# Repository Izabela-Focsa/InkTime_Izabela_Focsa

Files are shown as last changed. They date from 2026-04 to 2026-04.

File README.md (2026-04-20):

# InkTime Smartwatch - Dispozitiv Wearable Open Source (Stadiu EVT)

## 📌 Prezentare Generală

**InkTime** este un smartwatch open-source, proiectat în jurul microcontrolerului **Nordic nRF52840**, cu accent pe consum redus de energie, conectivitate Bluetooth Low Energy și modularitate hardware.

Acest repository conține:

* designul PCB (Fusion Electronics)
* fișierele pentru fabricație (Gerber, BOM, Pick & Place)
* designul mecanic (Fusion 360)
* integrarea sistemului pentru etapa EVT (Engineering Validation Test)

---

## 🧩 Diagrama Bloc a Sistemului

Arhitectura sistemului este centrată în jurul microcontrolerului nRF52840, care gestionează comunicația, afișajul și senzorii.

```
        +----------------------+
        |     Baterie LiPo     |
        +----------+-----------+
                   |
            +------v------+
            |  BQ25180    |  (Încărcare)
            +------+------+
                   |
            +------v------+
            |  RT6160A    |  (Regulator 3.3V)
            +------+------+
                   |
         +---------v---------+
         |    nRF52840 MCU   |
         | (BLE + Procesare) |
         +---+----+----+-----+
             |    |    |
        SPI  |    |    | I2C
             |    |    |
   +---------v+  |   +v-----------+
   | Display   |  |   | BMA423 IMU|
   | E-Paper   |  |   +------------+
   +----------+  |
                 |
             +---v---------+
             | MAX17048    |
             | Fuel Gauge  |
             +-------------+

             +-------------+
             | DRV2605L    |
             | Vibrații    |
             +-------------+

             +-------------+
             | Butoane     |
             +-------------+
```

---

## 🔌 Funcționalitatea Hardware (Detaliat)

### 🧠 Microcontroler – nRF52840

* ARM Cortex-M4F @ 64 MHz
* Bluetooth Low Energy 5.0 integrat
* Consum foarte redus în mod sleep

Roluri principale:

* procesare date senzori
* control display
* comunicare BLE

---

### 📺 Display – E-Paper

* Interfață: **SPI**
* Consum foarte mic
* Ideal pentru afișare permanentă

---

### ⚡ Managementul Energiei

#### 🔋 BQ25180

* gestionează încărcarea bateriei LiPo
* alimentare prin USB (VBUS)

#### 🔌 RT6160A

* convertor Buck-Boost
* furnizează **3.3V stabil**
* permite funcționarea chiar și la tensiuni scăzute ale bateriei

---

### 📊 Senzori și Actuatori

#### BMA423 (Accelerometru)

* interfață I2C
* detectare mișcare / pași

#### MAX17048 (Fuel Gauge)

* monitorizare nivel baterie
* consum foarte redus

#### DRV2605L (Driver Haptic)

* controlează motorul de vibrații
* suportă feedback haptic avansat

---

### 🎮 Input Utilizator

* 3 butoane: UP / ENTER / DOWN
* conectate ca GPIO cu rezistențe pull-up interne

---

## 🔗 Mapare Pini nRF52840

| Componentă | Pini | Interfață | Motiv |
| --- | --- | --- | --- |
| **Display E-Paper** | P0.28 (SCK), P0.29 (MOSI), P0.30 (CS), P0.31 (D/C), P0.02 (RST), P0.03 (BUSY) | SPI | Transfer rapid de date |
| **Butoane** | P0.08, P0.11, P0.12 | GPIO | Input simplu |
| **Haptic Driver** | P0.16 | GPIO/PWM  | Control vibrații |
| **Senzori I2C** | P0.14 (SDA), P0.15 (SCL) | I2C | Magistrală comună |
| **Fuel Gauge** | I2C | I2C | Monitorizare baterie |

---

## 📦 Bill of Materials (BOM)

| Ref  | Componentă | Link JLCPCB | Datasheet |
| ---- | --- | --- | --- |
| U1 | nRF52840 | https://jlcpcb.com/partdetail/Nordic-nRF52840 | https://infocenter.nordicsemi.com/pdf/nRF52840_PS_v1.1.pdf |
| U2 | DRV2605L | https://jlcpcb.com/partdetail/TexasInstruments-DRV2605L | https://www.ti.com/lit/ds/symlink/drv2605l.pdf |
| U3 | MAX17048 | https://jlcpcb.com/partdetail/MaximIntegrated-MAX17048  | https://datasheets.maximintegrated.com/en/ds/MAX17048-MAX17049.pdf |
| IC1  | BQ25180 | https://jlcpcb.com/partdetail/TexasInstruments-BQ25180  | https://www.ti.com/lit/ds/symlink/bq25180.pdf |
| IC2  | BMA423 | https://jlcpcb.com/partdetail/Bosch-BMA423 | https://www.bosch-sensortec.com/media/boschsensortec/downloads/datasheets/bst-bma423-ds000.pdf |
| IC3  | RT6160A | https://jlcpcb.com/partdetail/Richtek-RT6160A | https://www.richtek.com/assets/product_file/RT6160A/DS6160A-00.pdf |
| ANT1 | Antenă BLE | https://jlcpcb.com | |

---

## ⚙️ Constrângeri și Decizii de Design

### PCB

* trasee alimentare: **0.3 mm**
* trasee semnal: **0.15 mm**
* PCB pe 2 straturi

### RF

* plan de masă continuu
* zonă fără cupru sub antenă

### Decuplare

* condensatori 100nF la <1mm de fiecare IC

### Mecanic

* toate componentele pe **TOP layer**
* design compact pentru carcasă

---

## 🔋 Estimare Consum Energetic

| Mod | Consum |
| --- | --- |
| Activ (BLE + display) | ~15–20 mA |
| Idle | ~2–5 mA |
| Sleep | <10 µA |

Baterie: ~200–300 mAh
Autonomie estimată: **2–5 zile**

---

## 🖼️ Randări și Design

Randările dispozitivului, ale PCB-ului și integrarea în carcasă pot fi găsite în folderul dedicat din repository:

👉 [Images Folder](./Images)

---

## 🛠️ Fișiere pentru Fabricație

* Gerber
* Drill files
* Pick & Place (.csv)
* BOM (.csv)

---

## 📘 Design Log

* realizare schemă electronică
* rutare PCB completă
* verificare DRC
* integrare mecanică finală

---

## 📄 Licență

Proiectul este licențiat sub **GNU General Public License v3.0**.

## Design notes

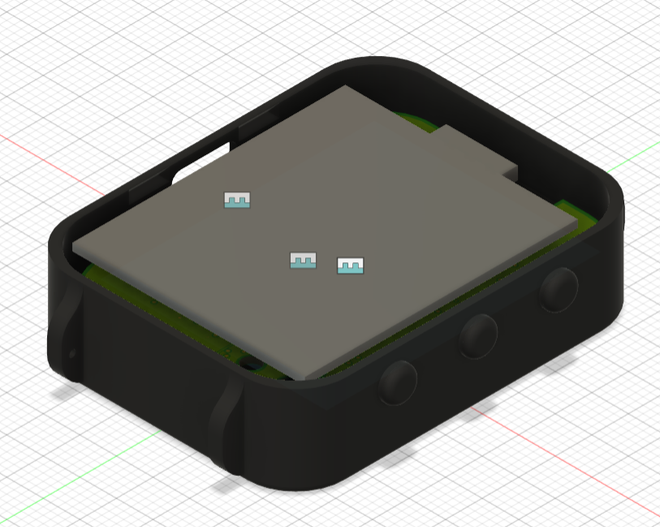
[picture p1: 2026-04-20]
Images/Cu display.png

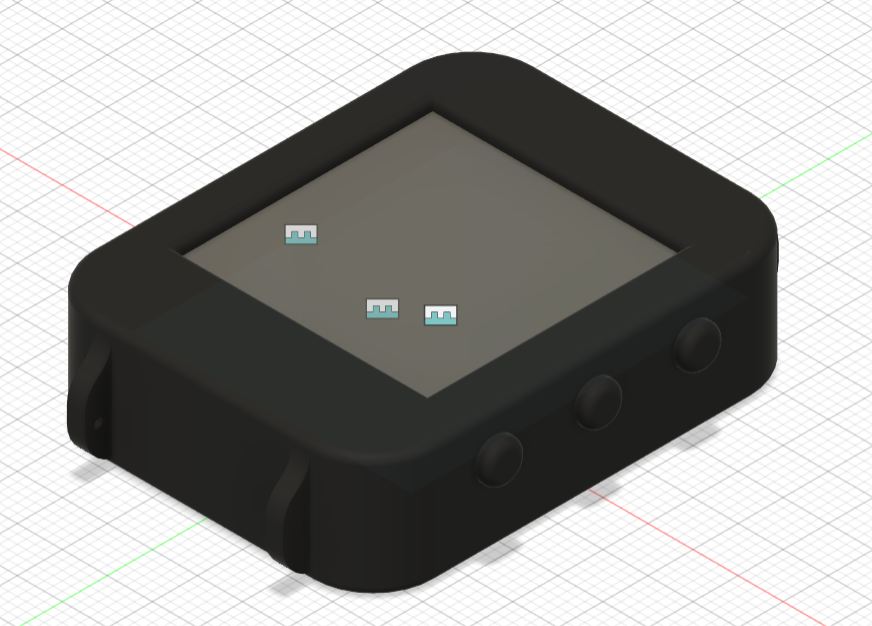
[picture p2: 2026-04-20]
Images/Cu carcasa.png

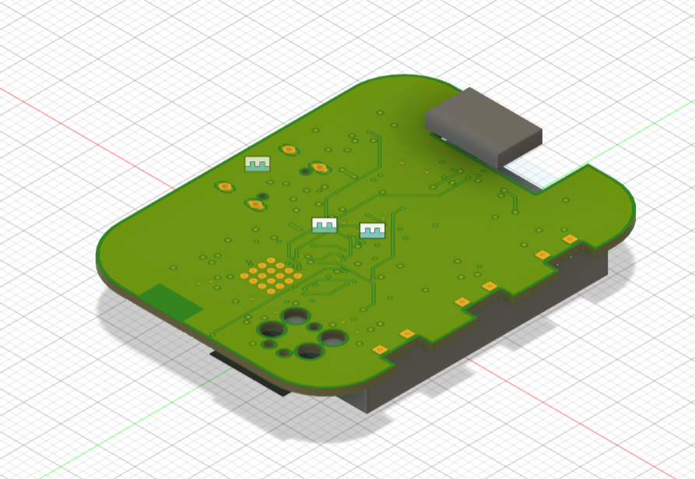
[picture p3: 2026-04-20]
Images/Placa.png

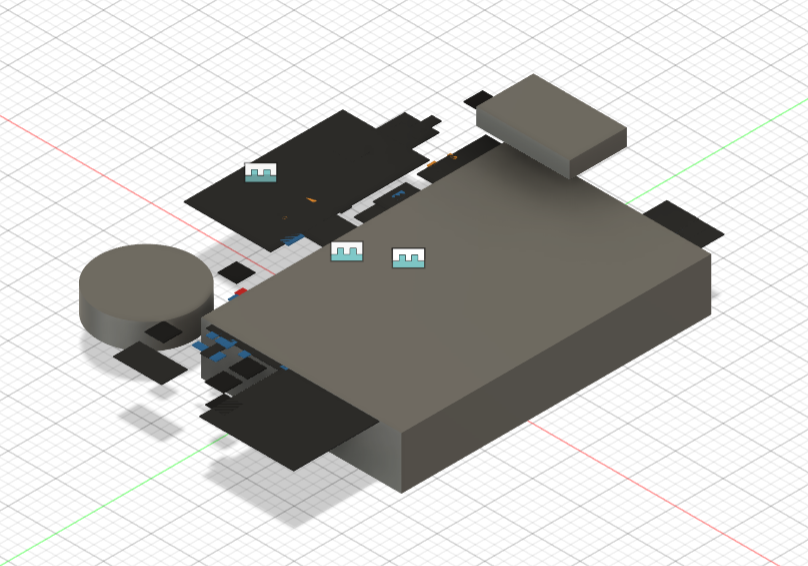
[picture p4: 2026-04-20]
Images/Packages.png

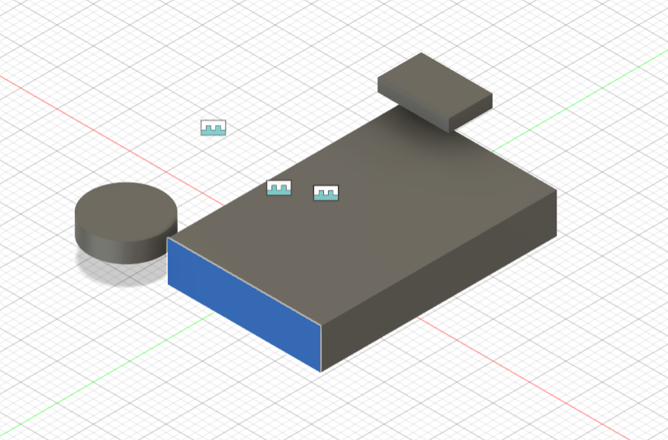
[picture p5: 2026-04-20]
Images/Baterie.png

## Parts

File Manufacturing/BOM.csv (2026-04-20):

Reference Designators | Quantity | Description | Package | Value | Manufacturer | Manufacturer Part Number | Vendor | Vendor Part Number | Top/Bottom
 | 1 | Board | Board
ANT1 | 1 | Antennas 2.45GHz ANTENNA | 2450AT18B100E_ANTC3216X140N | 2450AT18B100E |  |  |  |  | Top
C1, C2, C17, C18 | 4 | Generic chip capacitor | NORDIC_NRF_3_RESC0201_L | 12pF |  |  |  |  | Top
C1-EP-DR | 1 | Generic chip capacitor | NORDIC_NRF_3_RESC0402_L | 10uF |  |  |  |  | Top
C2-EP-DR | 1 | Generic chip capacitor | NORDIC_NRF_3_RESC0402_L | 4.7uF/25V |  |  |  |  | Top
C3, C4 | 2 | Generic chip capacitor | NORDIC_NRF_3_RESC0201_L | 1pF |  |  |  |  | Top
C5, C7, C8, C12, C19 | 5 | Generic chip capacitor | NORDIC_NRF_3_RESC0201_L | 100nF |  |  |  |  | Top
C6, C14, C20, C21 | 4 | Generic chip capacitor | NORDIC_NRF_3_RESC0402_L | 4.7µF |  |  |  |  | Top
C9 | 1 | Generic chip capacitor | NORDIC_NRF_3_RESC0201_L | 820pF |  |  |  |  | Top
C10, C13, C22 | 3 | Generic chip capacitor | NORDIC_NRF_3_RESC0201_L | N.C. |  |  |  |  | Top
C11 | 1 | Generic chip capacitor | NORDIC_NRF_3_RESC0201_L | 100pF |  |  |  |  | Top
C15 | 1 | Generic chip capacitor | NORDIC_NRF_3_RESC0402_L | 1.0µF |  |  |  |  | Top
C16 | 1 | Generic chip capacitor | NORDIC_NRF_3_RESC0201_L | 47nF |  |  |  |  | Top
C23, C27, C34, C42 | 4 | Check availability | CAPC0201X13N | 0.1uF |  |  |  |  | Top
C24 | 1 | Generic chip capacitor | NORDIC_NRF_3_RESC0201_L | 10uF |  |  |  |  | Top
C25, C33 | 2 | Generic chip capacitor | NORDIC_NRF_3_RESC0201_L | 22uF |  |  |  |  | Top
C29, C30, C31, C32, C37, C38 | 6 | Check availability | CAPC0201X13N | 1uF |  |  |  |  | Top
C39 | 1 | 0402 (1005 Metric) | PERFECT_0402_0402 | 10uF |  |  |  |  | Top
C43 | 1 | Generic chip capacitor | NORDIC_NRF_3_RESC0402_L | 4.7uF |  |  |  |  | Top
D2, D4, D5 | 3 | ON SEMICONDUCTOR - MBR0530 - DIODE, SCHOTTKY, 0.5A, 30V, SOD-123 | SOD3716X135N | MBR0530 |  |  |  |  | Top
D3 | 1 | Low Cap. ESD Protection Auto SOT-23-6 STMicroelectronics USBLC6-2SC6Y, Dual Uni-Directional TVS Diode Array, 6-Pin SOT-23 | SOT95P280X145-6N | USBLC6-2SC6Y |  |  |  |  | Top
EPD_C1, EPD_C2 | 2 | Generic chip capacitor | NORDIC_NRF_3_RESC0201_L | 1uF/50V |  |  |  |  | Top
EPD_C5 | 1 | Generic chip capacitor | NORDIC_NRF_3_RESC0201_L | 0.1uF/50V |  |  |  |  | Top
EPD_C6, EPD_C7, EPD_C8, EPD_C9, EPD_C10, EPD_C11, EPD_C12 | 7 | Generic chip capacitor | NORDIC_NRF_3_RESC0402_L | 1uF/50V |  |  |  |  | Top
IC1 | 1 | Charger IC Lithium Ion/Polymer, Lithium Iron Phosphate 8-DSBGA (1.6x1.1) | BQ25180YBGR_BGA8C40P2X4_100X155X50 | BQ25180YBGR_BQ25180YBGR |  |  |  |  | Top
IC2 | 1 | Haptic Driver for ERM/LRA with Built-In Library and Smart Loop Architecture | DRV2605YZFR_BGA9C50P3X3_144X144X62 | DRV2605YZFR |  |  |  |  | Top
IC3 | 1 | Accelerometers Triaxial low-g 12bit Acceleration Sensor | BMA423_BMA423 | BMA421 |  |  |  |  | Top
IC9 | 1 | Buck-Boost Regulator Positive Output Step-Up/Step-Down I2C DC-DC Controller IC 15-WL-CSP (BSC) (1.4x2.3) | RT6160AWSC_BGA15C40P3X5_140X230X60 | RT6160AWSC |  |  |  |  | Top
J1 | 1 | FFC & FPC Connectors 0.5mm FPC RA SMT Dual Contact 24Ckt | 503480-2400_5034802400 | 503480-2400 |  |  |  |  | Top
J2 | 1 | CABLE ADAPTER 6 POS | TC2030-IDC_TC2030IDC | TC2030-IDC |  |  |  |  | Top
J4 | 1 | Check availability | KINGHELM_KH-TYPE-C-16P | KH-TYPE-C-16P |  |  |  |  | Top
L1 | 1 | Generic chip inductor | NORDIC_NRF_2_RESC0402_L | 3.9nH |  |  |  |  | Top
L2 | 1 | Generic chip inductor | NORDIC_NRF_2_RESC0402_L | 10µH |  |  |  |  | Top
L3 | 1 | Generic chip inductor | NORDIC_NRF_2_RESC0402_L | 15nH |  |  |  |  | Top
L5 | 1 |  | ESP32_C6_LIBRARY_2_IND_4828-WE-TPC_WRE | 68uH |  |  |  |  | Top
L7 | 1 | SMD / SMT Inductors (Coils), L=0.47?H, L x W x T : | MLP2016SR47MT0S1_INDC2016X100N | FTC252012SR47MBCA |  |  |  |  | Top
Q1 | 1 | P-channel MOSFETs | ESP32_WROVER_SPARKFUN-DISCRETESEMI_SOT23-3 | 20V/4.2A/52mΩ/1.4W |  |  |  |  | Top
Q3 | 1 | MOSFET N-Ch 30V 1.5A TrenchFET SC70 Vishay Si1308EDL-T1-GE3 N-channel MOSFET Transistor, 1.5 A, 30 V, 3-Pin SC-70 | SOT65P210X110-3N | SI1308EDL-T1-GE3 |  |  |  |  | Top
R_PWR_EPD, R2_EP_DR | 2 | 7.68k 0201 Thin Film Surface Mount Fixed Resistor +/-0.5% 0.031W CPF0201D7K68C1 | CPF0201D7K68C1_0201 | 10K |  |  |  |  | Top
R_TYPE_SEL | 1 | 7.68k 0201 Thin Film Surface Mount Fixed Resistor +/-0.5% 0.031W CPF0201D7K68C1 | CPF0201D7K68C1_0201 | 2.2 |  |  |  |  | Top
R1_EP_ED | 1 | 7.68k 0201 Thin Film Surface Mount Fixed Resistor +/-0.5% 0.031W CPF0201D7K68C1 | CPF0201D7K68C1_0201 | 0.47 |  |  |  |  | Top
R1_USB, R2_USB | 2 | 7.68k 0201 Thin Film Surface Mount Fixed Resistor +/-0.5% 0.031W CPF0201D7K68C1 | CPF0201D7K68C1_0201 | 5K1 |  |  |  |  | Top
R2, R4 | 2 | 7.68k 0201 Thin Film Surface Mount Fixed Resistor +/-0.5% 0.031W CPF0201D7K68C1 | CPF0201D7K68C1_0201 | 0 |  |  |  |  | Top
R3 | 1 | 7.68k 0201 Thin Film Surface Mount Fixed Resistor +/-0.5% 0.031W CPF0201D7K68C1 | R0201 | 0 |  |  |  |  | Top
R5, R7, R8 | 3 | 7.68k 0201 Thin Film Surface Mount Fixed Resistor +/-0.5% 0.031W CPF0201D7K68C1 | R0201 | 10k |  |  |  |  | Top
R9 | 1 | 7.68k 0201 Thin Film Surface Mount Fixed Resistor +/-0.5% 0.031W CPF0201D7K68C1 | R0201 | 10K |  |  |  |  | Top
R17, R18 | 2 | 7.68k 0201 Thin Film Surface Mount Fixed Resistor +/-0.5% 0.031W CPF0201D7K68C1 | CPF0201D7K68C1_0201 | 3K3 |  |  |  |  | Top
SJ1 | 1 | SMD solder JUMPER | JUMPER_SJ | N.C |  |  |  |  | Top
SW_DN, SW_ENT, SW_UP | 3 |  | SW_EVP-AKE31A_PAN | 2025-10-22_07-23-44_LIBRARY_EVP-AKE31ASW_EVP-AKE31A_PAN |  |  |  |  | Top
TP_3.3V, TP_3V3, TP_BAT_GND, TP_GND, TP_ON, TP_OP, TP_RESET, TP_SCL, TP_SDA, TP_SWDCLK, TP_SWDIO, TP_SWO, TP_VBAT, TP_VREG | 14 | Test pad | HECTOR_WATCH_1_TP20R | HECTOR_WATCH_1_TPTP20R |  |  |  |  | Top
U1 | 1 | nRF52840 | NORDIC_NRF_4_AQFN50P700X700X85_HS-74N | NRF52840_QF |  |  |  |  | Top
U3 | 1 | Check availability | SON50P200X200X80-9N | MAX17048G+T10 |  |  |  |  | Top
X1 | 1 |  | NORDIC_NRF_BT-XTAL_2016_N | 32MHz |  |  |  |  | Top
X2 | 1 |  | NORDIC_NRF_1_XTAL_3215_N | 32.768kHz |  |  |  |  | Top

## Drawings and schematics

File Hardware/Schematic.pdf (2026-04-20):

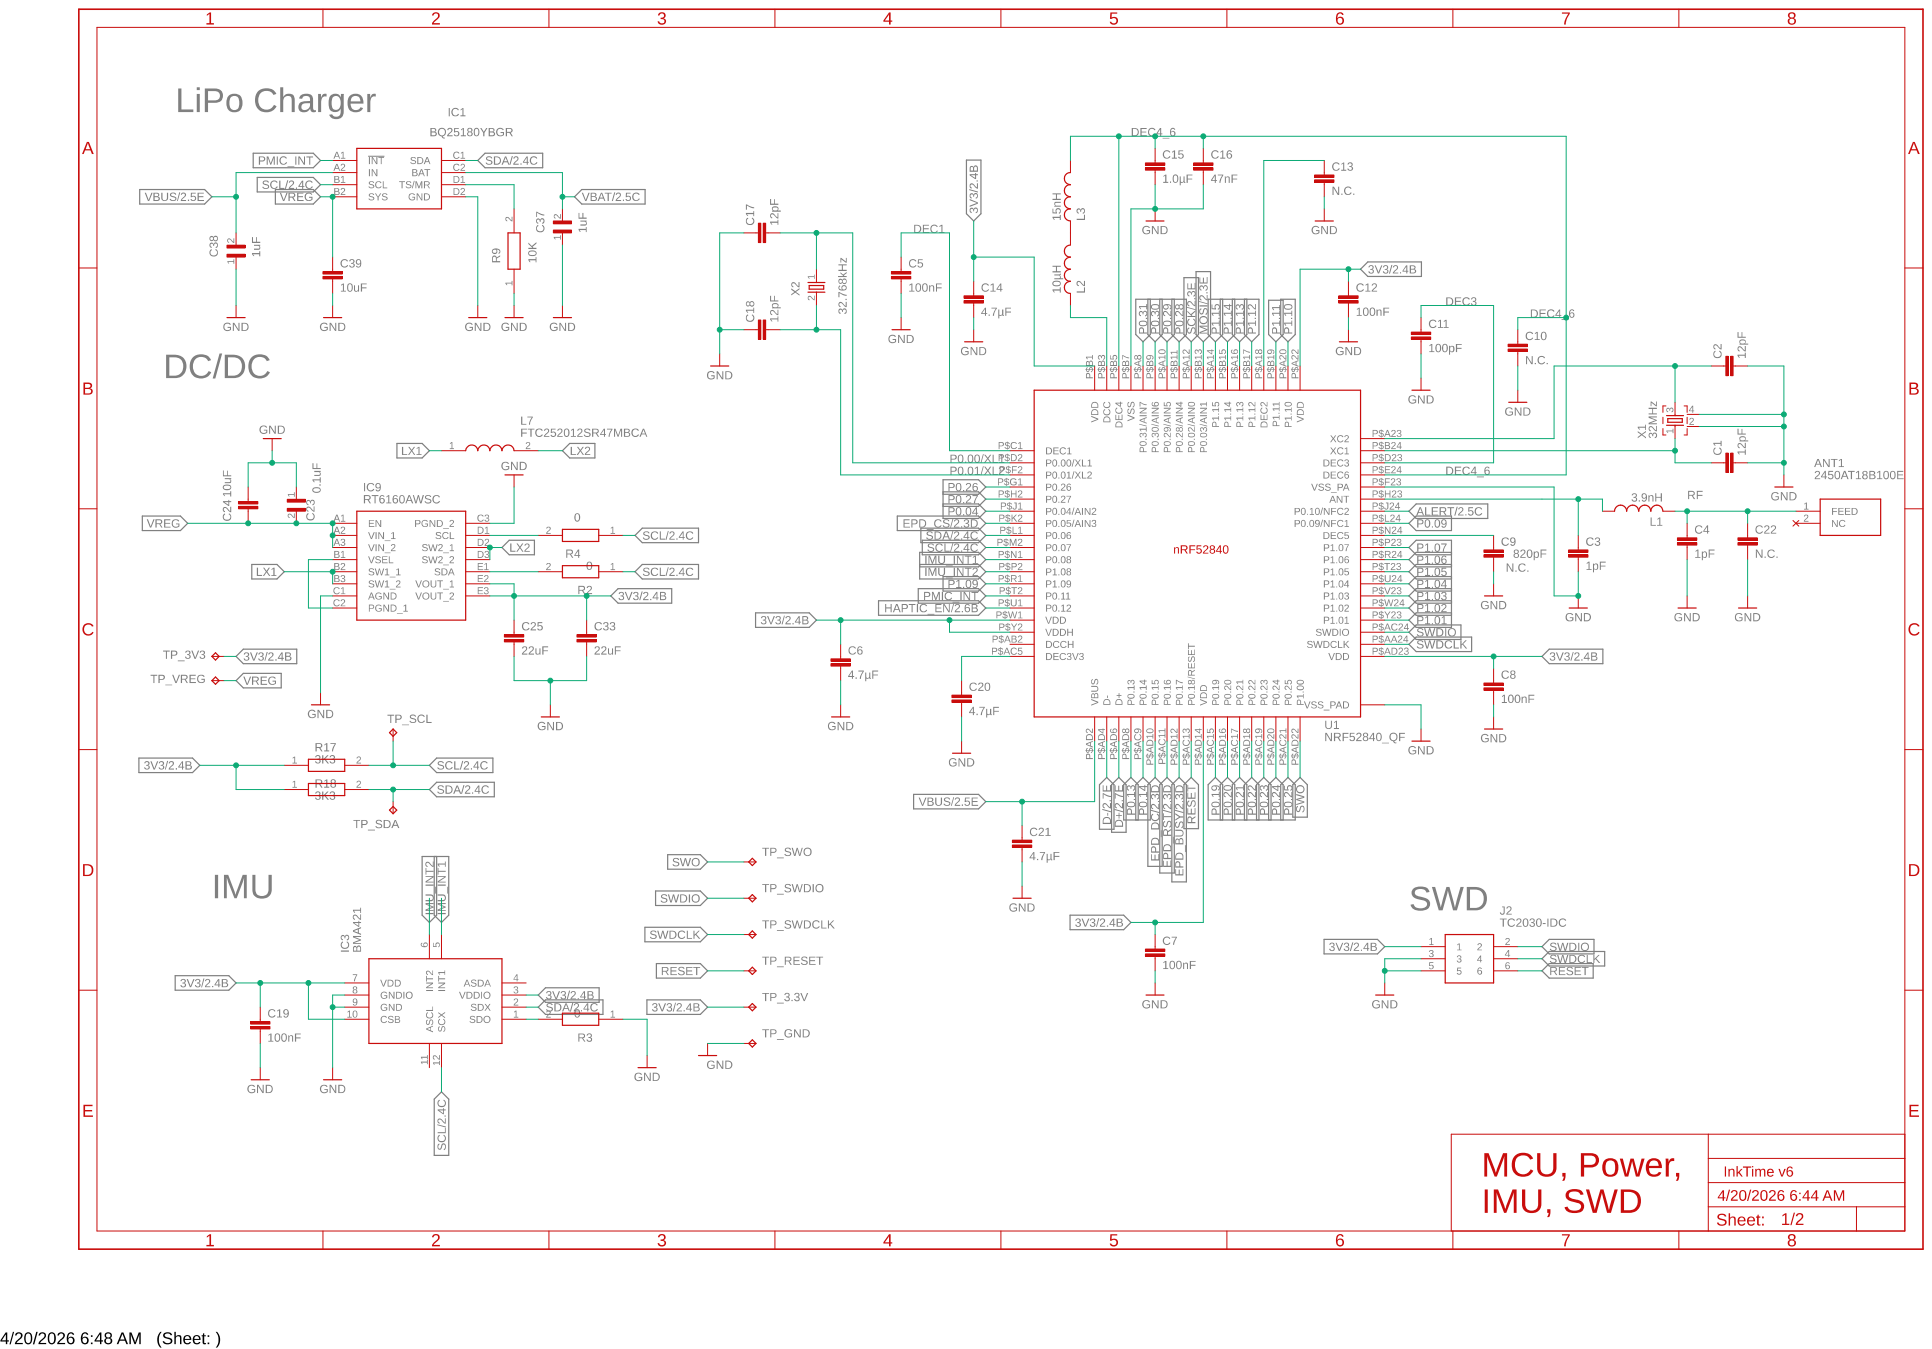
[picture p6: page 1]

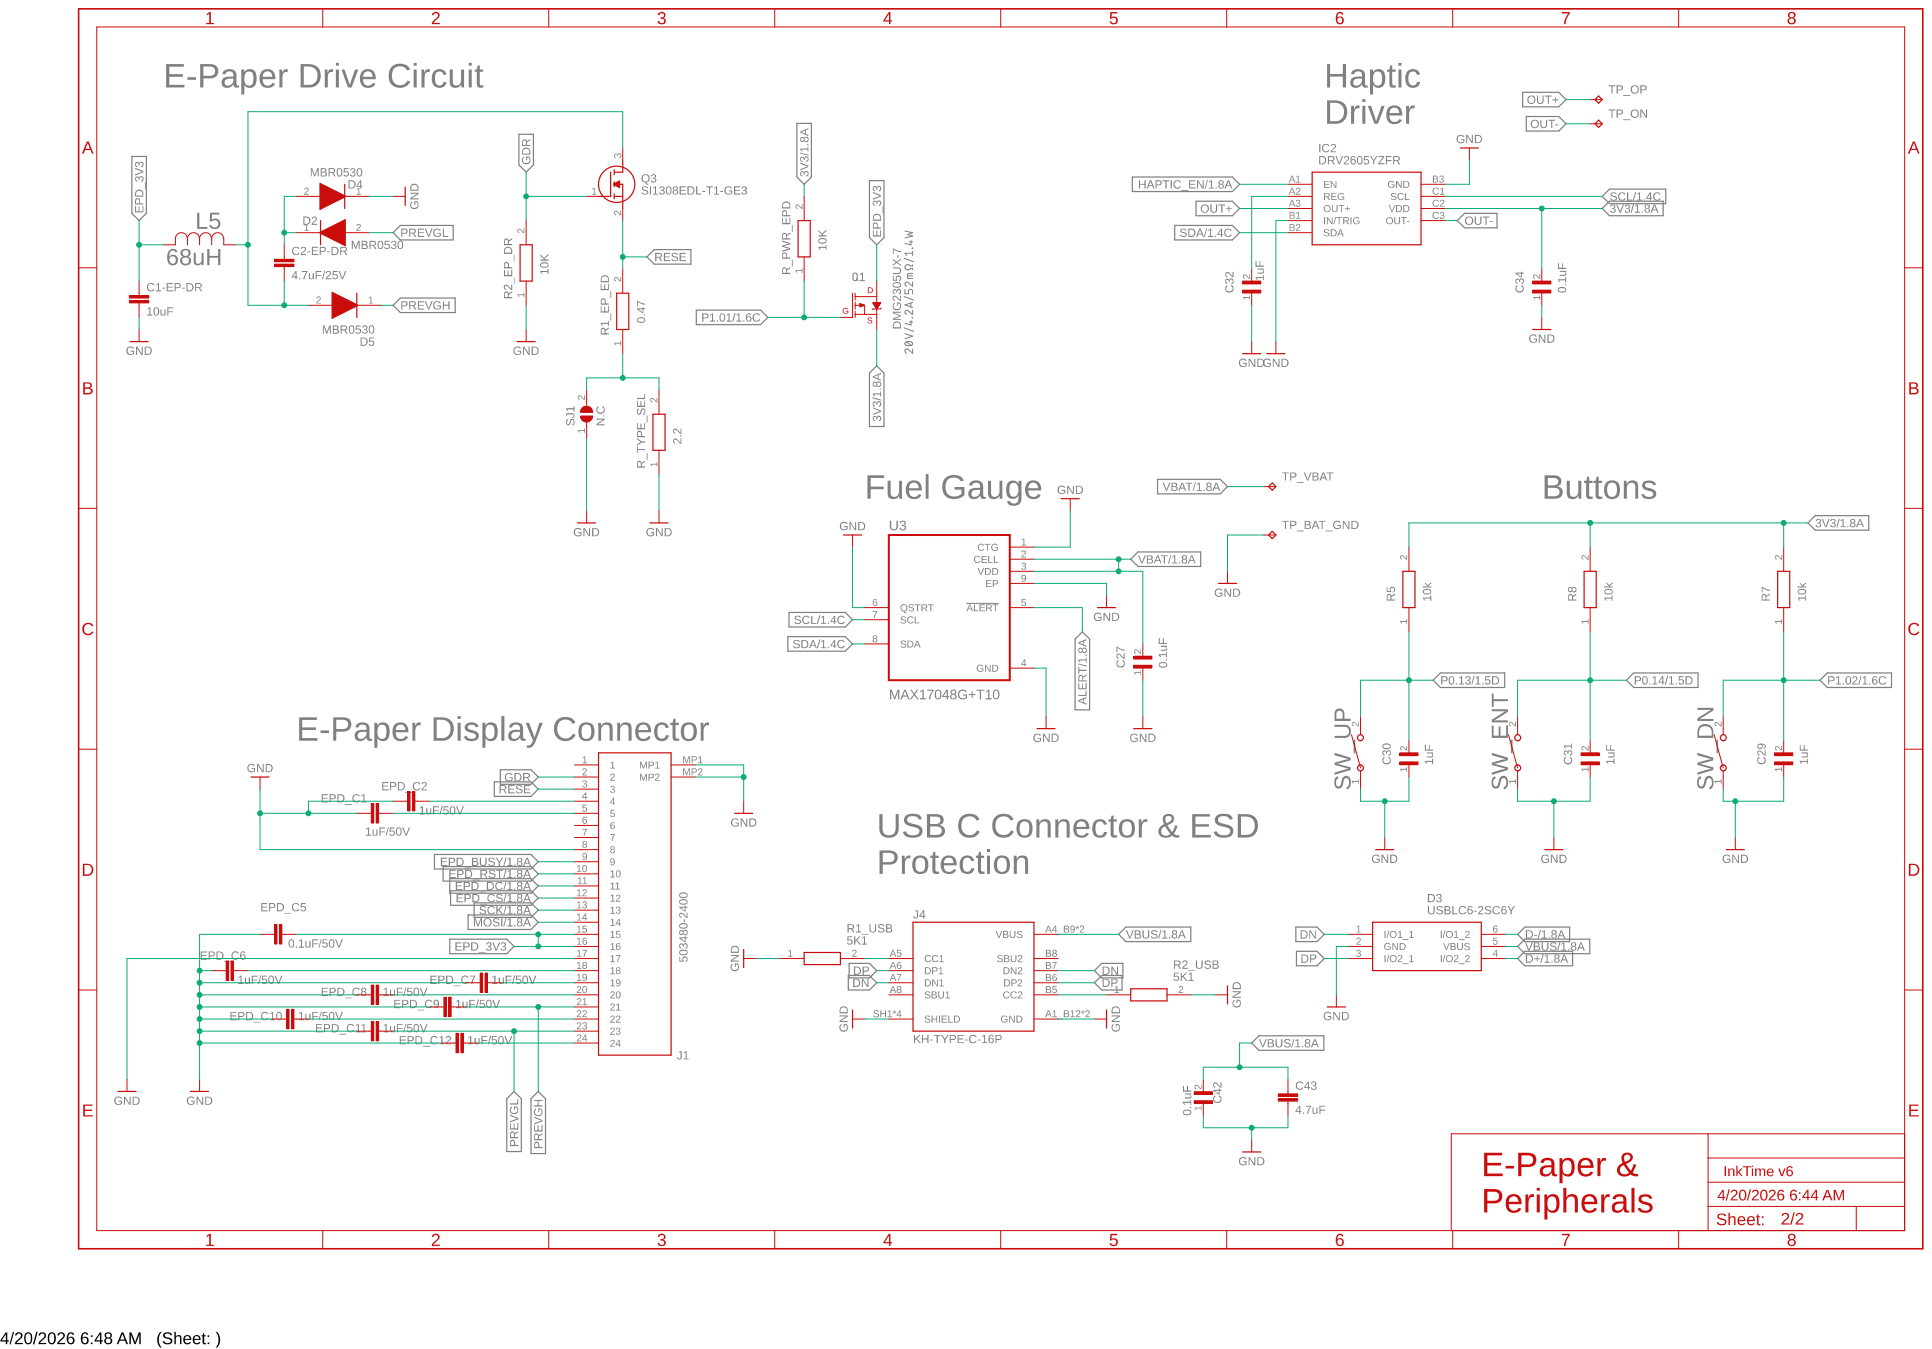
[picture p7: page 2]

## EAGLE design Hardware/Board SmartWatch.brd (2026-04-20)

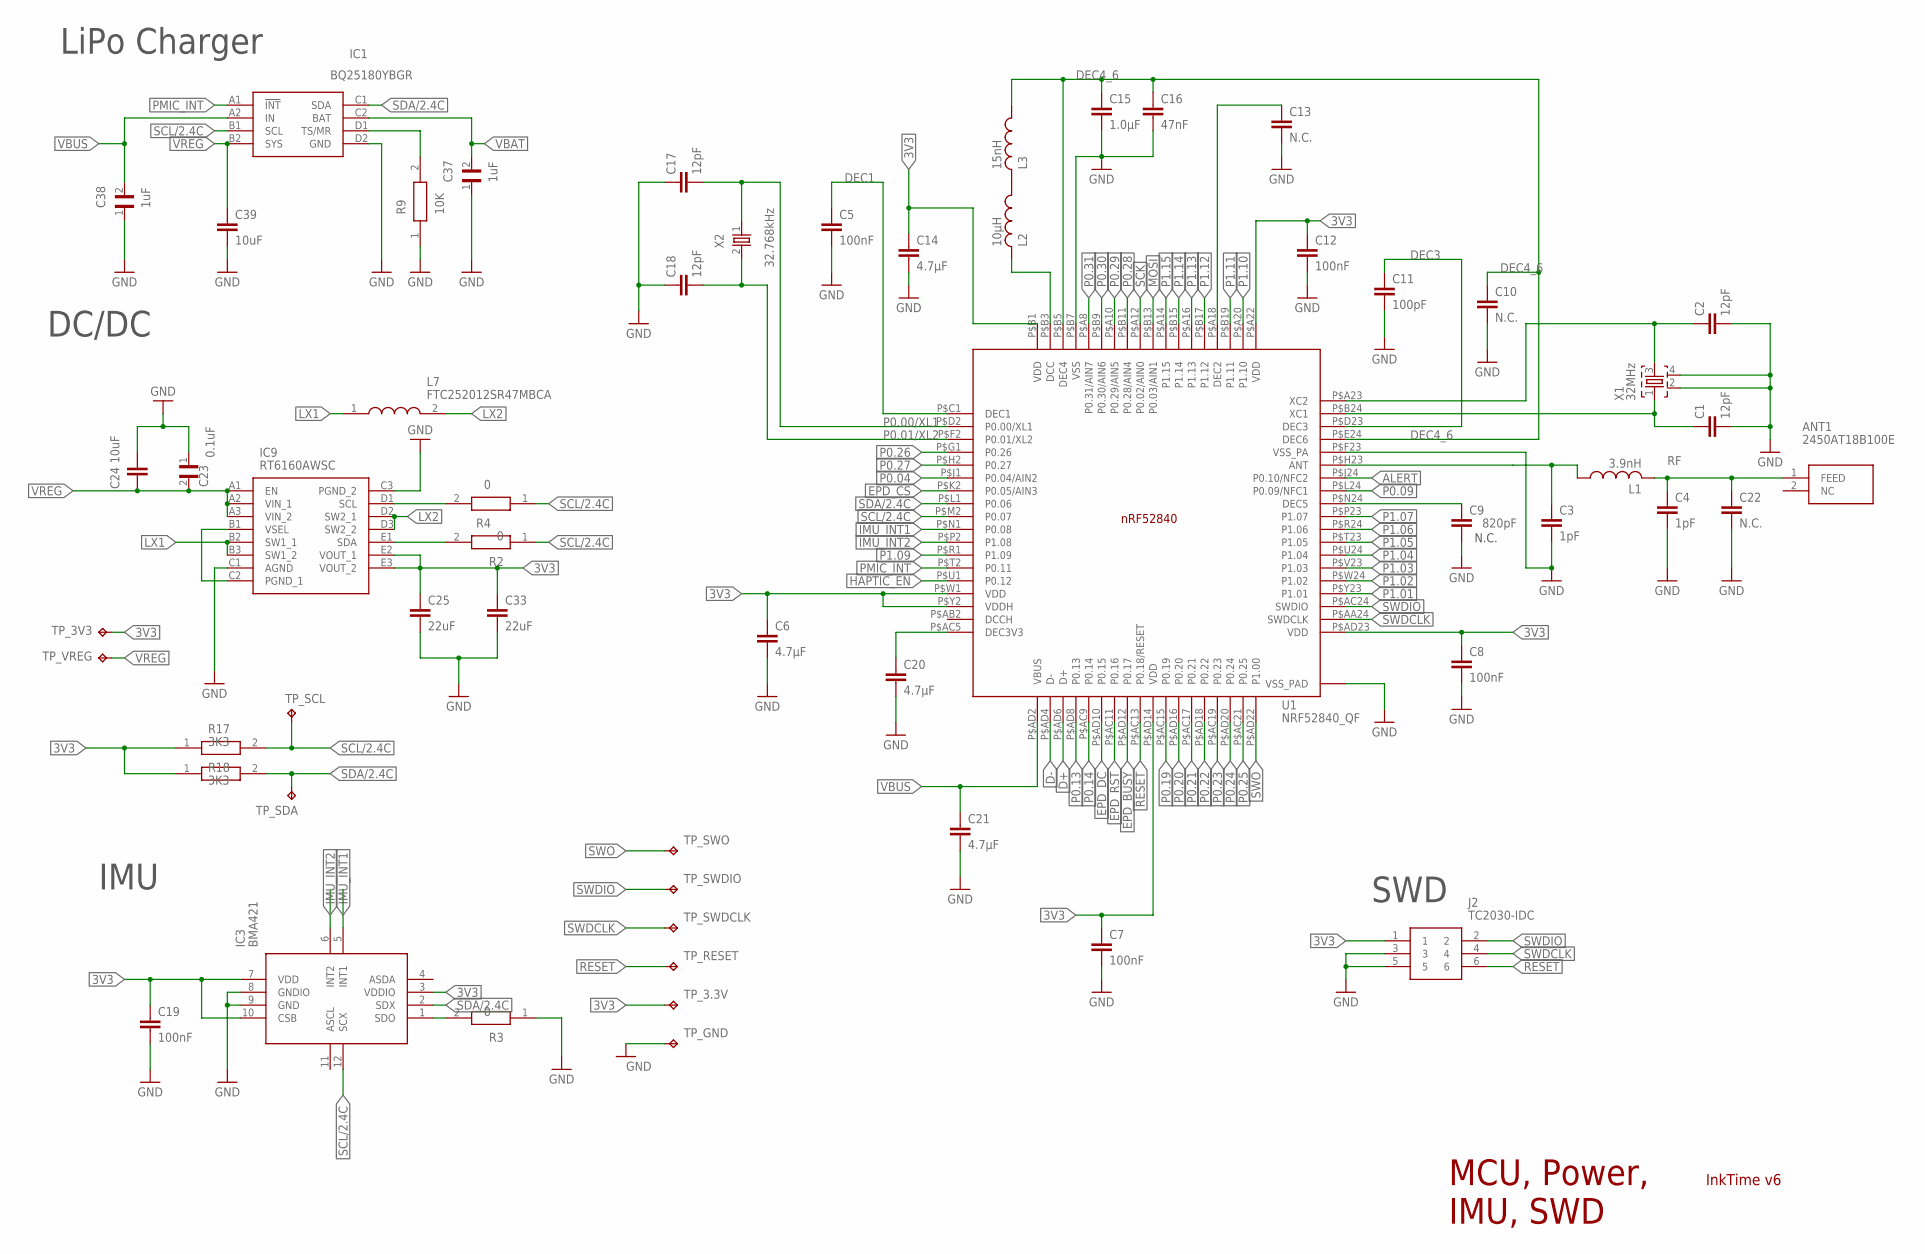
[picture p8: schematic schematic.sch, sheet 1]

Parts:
ANT1: 2450AT18B100E; 2450AT18B100E_ANTC3216X140N
C1, C2, C17, C18: 12pF; NORDIC_NRF_3_RESC0201_L
C3, C4: 1pF; NORDIC_NRF_3_RESC0201_L
C5, C7, C8, C12, C19: 100nF; NORDIC_NRF_3_RESC0201_L
C6, C14, C20, C21: 4.7µF; NORDIC_NRF_3_RESC0402_L
C9: 820pF; NORDIC_NRF_3_RESC0201_L
C10, C13, C22: N.C.; NORDIC_NRF_3_RESC0201_L
C11: 100pF; NORDIC_NRF_3_RESC0201_L
C15: 1.0µF; NORDIC_NRF_3_RESC0402_L
C16: 47nF; NORDIC_NRF_3_RESC0201_L
C23: 0.1uF; GRM011R60J152KE01L_2_CAPC0201X13N
C24: 10uF; NORDIC_NRF_3_RESC0201_L
C25, C33: 22uF; NORDIC_NRF_3_RESC0201_L
C37, C38: 1uF; GRM011R60J152KE01L_2_CAPC0201X13N
C39: 10uF; PERFECT_0402_0402
IC1: BQ25180YBGR_BQ25180YBGR; BQ25180YBGR_BGA8C40P2X4_100X155X50
IC3: BMA421; BMA423_BMA423
IC9: RT6160AWSC; RT6160AWSC_BGA15C40P3X5_140X230X60
J2: TC2030-IDC; TC2030-IDC_TC2030IDC
L1: 3.9nH; NORDIC_NRF_2_RESC0402_L
L2: 10µH; NORDIC_NRF_2_RESC0402_L
L3: 15nH; NORDIC_NRF_2_RESC0402_L
L7: FTC252012SR47MBCA; MLP2016SR47MT0S1_INDC2016X100N
R2, R4: 0; CPF0201D7K68C1_0201
R3: 0; ERA-1AEB3401C_0201
R9: 10K; ERA-1AEB3401C_0201
R17, R18: 3K3; CPF0201D7K68C1_0201
TP_3.3V, TP_3V3: HECTOR_WATCH_1_TPTP20R; HECTOR_WATCH_1_TP20R
TP_GND: HECTOR_WATCH_1_TPTP20R; HECTOR_WATCH_1_TP20R
TP_RESET: HECTOR_WATCH_1_TPTP20R; HECTOR_WATCH_1_TP20R
TP_SCL: HECTOR_WATCH_1_TPTP20R; HECTOR_WATCH_1_TP20R
TP_SDA: HECTOR_WATCH_1_TPTP20R; HECTOR_WATCH_1_TP20R
TP_SWDCLK: HECTOR_WATCH_1_TPTP20R; HECTOR_WATCH_1_TP20R
TP_SWDIO: HECTOR_WATCH_1_TPTP20R; HECTOR_WATCH_1_TP20R
TP_SWO: HECTOR_WATCH_1_TPTP20R; HECTOR_WATCH_1_TP20R
TP_VREG: HECTOR_WATCH_1_TPTP20R; HECTOR_WATCH_1_TP20R
U1: NRF52840_QF; NORDIC_NRF_4_AQFN50P700X700X85_HS-74N
X1: 32MHz; NORDIC_NRF_BT-XTAL_2016_N
X2: 32.768kHz; NORDIC_NRF_1_XTAL_3215_N

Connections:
3V3: C6.1, C7.1, C8.1, C12.1, C14.1, C19.1, C25.1, C33.1, IC3.3 (VDDIO), IC3.7 (VDD), IC3.10 (CSB), IC9.E2 (VOUT_1), IC9.E3 (VOUT_2), J2.1, R17.1, R18.1, TP_3.3V.TP, TP_3V3.TP, U1.P$A22 (VDD), U1.P$AD14 (VDD), U1.P$AD23 (VDD), U1.P$B1 (VDD), U1.P$W1 (VDD), U1.P$Y2 (VDDH); also elsewhere on the board
ALERT: U1.P$J24 (P0.10/NFC2); also elsewhere on the board
D+: U1.P$AD6 (D+); also elsewhere on the board
D-: U1.P$AD4 (D-); also elsewhere on the board
DEC1: C5.1, U1.P$C1 (DEC1)
DEC3: C11.1, U1.P$D23 (DEC3)
DEC4_6: C10.1, C15.1, C16.1, L3.1, U1.P$B5 (DEC4), U1.P$E24 (DEC6)
EPD_BUSY: U1.P$AD12 (P0.17); also elsewhere on the board
EPD_CS: U1.P$K2 (P0.05/AIN3); also elsewhere on the board
EPD_DC: U1.P$AD10 (P0.15); also elsewhere on the board
EPD_RST: U1.P$AC11 (P0.16); also elsewhere on the board
GND: C1.2, C2.2, C3.2, C4.2, C5.2, C6.2, C7.2, C8.2, C9.2, C10.2, C11.2, C12.2, C13.2, C14.2, C15.2, C16.2, C17.1, C18.1, C19.2, C20.2, C21.2, C22.2, C23.1, C24.1, C25.2, C33.2, C37.1, C38.1, C39.2, IC1.D2 (GND), IC3.8 (GNDIO), IC3.9 (GND), IC9.C1 (AGND), IC9.C3 (PGND_2), J2.3, J2.5, R3.1, R9.1, TP_GND.TP, U1.P$74 (VSS_PAD), U1.P$75 (VSS_PAD), U1.P$76 (VSS_PAD), U1.P$77 (VSS_PAD), U1.P$78 (VSS_PAD), U1.P$79 (VSS_PAD), U1.P$80 (VSS_PAD), U1.P$81 (VSS_PAD), U1.P$82 (VSS_PAD), U1.P$83 (VSS_PAD), U1.P$84 (VSS_PAD), U1.P$85 (VSS_PAD), U1.P$86 (VSS_PAD), U1.P$87 (VSS_PAD), U1.P$88 (VSS_PAD), U1.P$89 (VSS_PAD), U1.P$90 (VSS_PAD), U1.P$B7 (VSS), U1.P$F23 (VSS_PA), X1.2, X1.4; also elsewhere on the board
HAPTIC_EN: U1.P$U1 (P0.12); also elsewhere on the board
IMU_INT1: IC3.5 (INT1), U1.P$N1 (P0.08)
IMU_INT2: IC3.6 (INT2), U1.P$P2 (P1.08)
LX1: IC9.B2 (SW1_1), IC9.B3 (SW1_2), L7.1
LX2: IC9.D2 (SW2_1), IC9.D3 (SW2_2), L7.2
MOSI: U1.P$B13 (P0.03/AIN1); also elsewhere on the board
unnamed: IC9.B1 (VSEL), IC9.C2 (PGND_1)
unnamed: C3.1, L1.1, U1.P$H23 (ANT)
unnamed: C1.1, U1.P$B24 (XC1), X1.1
unnamed: C2.1, U1.P$A23 (XC2), X1.3
unnamed: IC9.D1 (SCL), R4.2
unnamed: IC1.D1 (TS/MR), R9.2
unnamed: IC3.1 (SDO), R3.2
unnamed: IC9.E1 (SDA), R2.2
unnamed: L2.2, U1.P$B3 (DCC)
unnamed: L2.1, L3.2
unnamed: C20.1, U1.P$AC5 (DEC3V3)
unnamed: C9.1, U1.P$N24 (DEC5)
unnamed: C13.1, U1.P$A18 (DEC2)
P0.00/XL1: C17.2, U1.P$D2 (P0.00/XL1), X2.1
P0.01/XL2: C18.2, U1.P$F2 (P0.01/XL2), X2.2
P0.04: U1.P$J1 (P0.04/AIN2)
P0.09: U1.P$L24 (P0.09/NFC1)
P0.13: U1.P$AD8 (P0.13)
P0.14: U1.P$AC9 (P0.14)
P0.19: U1.P$AC15 (P0.19)
P0.20: U1.P$AD16 (P0.20)
P0.21: U1.P$AC17 (P0.21)
P0.22: U1.P$AD18 (P0.22)
P0.23: U1.P$AC19 (P0.23)
P0.24: U1.P$AD20 (P0.24)
P0.25: U1.P$AC21 (P0.25)
P0.26: U1.P$G1 (P0.26)
P0.27: U1.P$H2 (P0.27)
P0.28: U1.P$B11 (P0.28/AIN4)
P0.29: U1.P$A10 (P0.29/AIN5)
P0.30: U1.P$B9 (P0.30/AIN6)
P0.31: U1.P$A8 (P0.31/AIN7)
P1.01: U1.P$Y23 (P1.01)
P1.02: U1.P$W24 (P1.02)
P1.03: U1.P$V23 (P1.03)
P1.04: U1.P$U24 (P1.04)
P1.05: U1.P$T23 (P1.05)
P1.06: U1.P$R24 (P1.06)
P1.07: U1.P$P23 (P1.07)
P1.09: U1.P$R1 (P1.09)
P1.10: U1.P$A20 (P1.10)
P1.11: U1.P$B19 (P1.11)
P1.12: U1.P$B17 (P1.12)
P1.13: U1.P$A16 (P1.13)
P1.14: U1.P$B15 (P1.14)
P1.15: U1.P$A14 (P1.15)
PMIC_INT: IC1.A1 (!INT), U1.P$T2 (P0.11)
RESET: J2.6, TP_RESET.TP, U1.P$AC13 (P0.18/RESET)
RF: ANT1.1 (FEED), C4.1, C22.1, L1.2
SCK: U1.P$A12 (P0.02/AIN0); also elsewhere on the board
SCL/2.4C: IC1.B1 (SCL), IC3.12 (SCX), R2.1, R4.1, R17.2, TP_SCL.TP, U1.P$M2 (P0.07)
SDA/2.4C: IC1.C1 (SDA), IC3.2 (SDX), R18.2, TP_SDA.TP, U1.P$L1 (P0.06)
SWDCLK: J2.4, TP_SWDCLK.TP, U1.P$AA24 (SWDCLK)
SWDIO: J2.2, TP_SWDIO.TP, U1.P$AC24 (SWDIO)
SWO: TP_SWO.TP, U1.P$AD22 (P1.00)
VBAT: C37.2, IC1.C2 (BAT); also elsewhere on the board
VBUS: C21.1, C38.2, IC1.A2 (IN), U1.P$AD2 (VBUS); also elsewhere on the board
VREG: C23.2, C24.2, C39.1, IC1.B2 (SYS), IC9.A1 (EN), IC9.A2 (VIN_1), IC9.A3 (VIN_2), TP_VREG.TP

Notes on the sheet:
N.C.
LiPo Charger
DC/DC
IMU
SWD
MCU, Power, IMU, SWD
InkTime v6

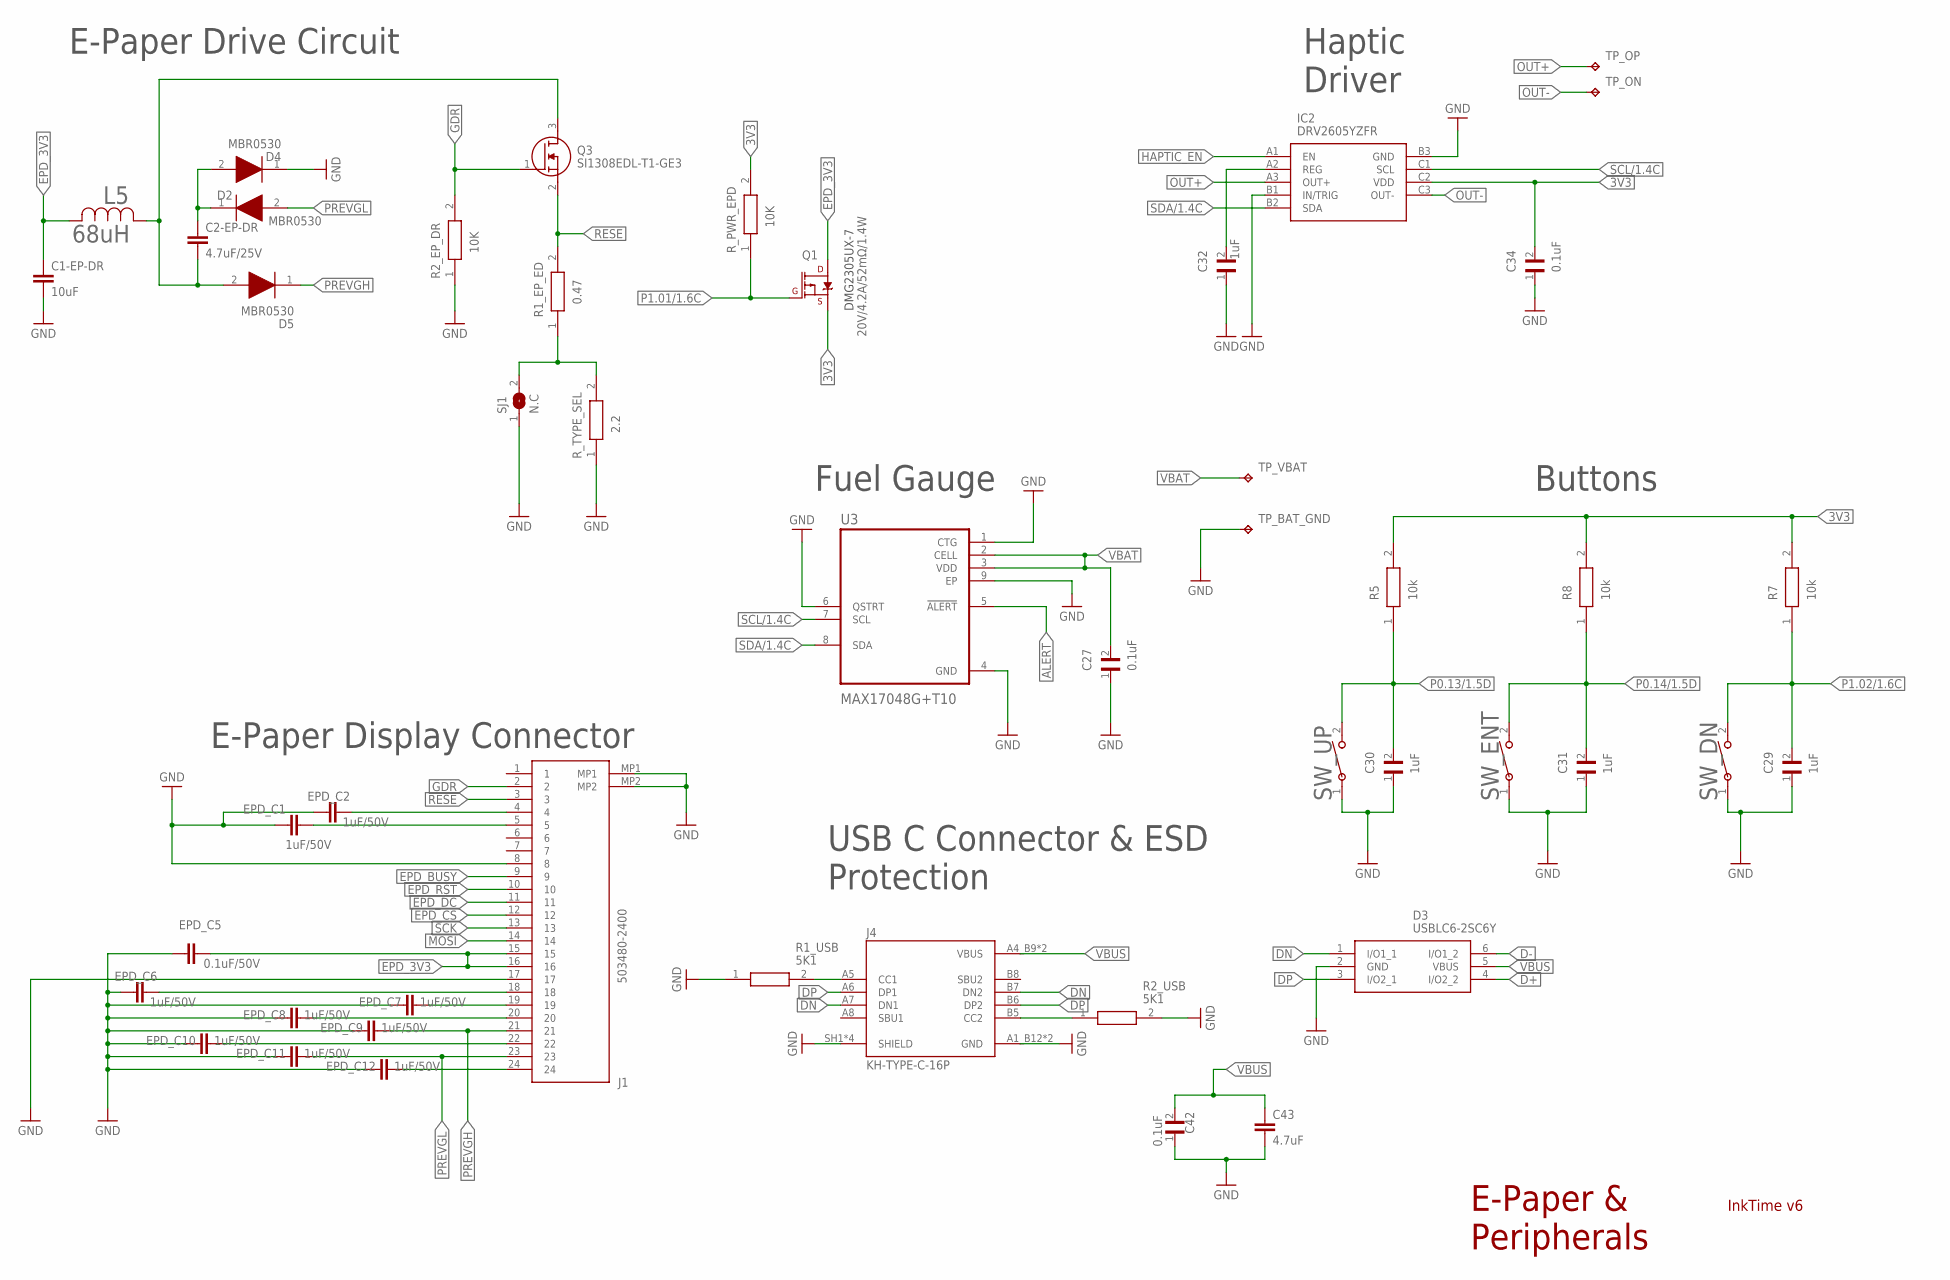
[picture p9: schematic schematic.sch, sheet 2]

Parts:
C1-EP-DR: 10uF; NORDIC_NRF_3_RESC0402_L
C2-EP-DR: 4.7uF/25V; NORDIC_NRF_3_RESC0402_L
C27, C34, C42: 0.1uF; GRM011R60J152KE01L_2_CAPC0201X13N
C29, C30, C31, C32: 1uF; GRM011R60J152KE01L_2_CAPC0201X13N
C43: 4.7uF; NORDIC_NRF_3_RESC0402_L
D2, D4, D5: MBR0530; ESP32_C6_LIBRARY_5_SOD3716X135N
D3: USBLC6-2SC6Y; ESP32_C6_LIBRARY_3_SOT95P280X145-6N
EPD_C1, EPD_C2: 1uF/50V; NORDIC_NRF_3_RESC0201_L
EPD_C5: 0.1uF/50V; NORDIC_NRF_3_RESC0201_L
EPD_C6, EPD_C7, EPD_C8, EPD_C9, EPD_C10, EPD_C11, EPD_C12: 1uF/50V; NORDIC_NRF_3_RESC0402_L
IC2: DRV2605YZFR; DRV2605YZFR_BGA9C50P3X3_144X144X62
J1: 503480-2400; 503480-2400_5034802400
J4: KH-TYPE-C-16P; KH-TYPE-C-16P_KINGHELM_KH-TYPE-C-16P
L5: 68uH; ESP32_C6_LIBRARY_2_IND_4828-WE-TPC_WRE
Q1: 20V/4.2A/52mΩ/1.4W; ESP32_C6_LIBRARY_4_ESP32_C6_LIBRARY_4_ESP32_C6_LIBRARY_4_ES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
Q3: SI1308EDL-T1-GE3; ESP32_C6_LIBRARY_6_SOT65P210X110-3N
R1_EP_ED: 0.47; CPF0201D7K68C1_0201
R1_USB, R2_USB: 5K1; CPF0201D7K68C1_0201
R2_EP_DR: 10K; CPF0201D7K68C1_0201
R5, R7, R8: 10k; ERA-1AEB3401C_0201
R_PWR_EPD: 10K; CPF0201D7K68C1_0201
R_TYPE_SEL: 2.2; CPF0201D7K68C1_0201
SJ1: N.C; ESP32_C6_LIBRARY_7_JUMPER_SJ
SW_DN: 2025-10-22_07-23-44_LIBRARY_EVP-AKE31ASW_EVP-AKE3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; 2025-10-22_07-23-44_LIBRARY_SW_EVP-AKE31A_PAN
SW_ENT: 2025-10-22_07-23-44_LIBRARY_EVP-AKE31ASW_EVP-AKE3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; 2025-10-22_07-23-44_LIBRARY_SW_EVP-AKE31A_PAN
SW_UP: 2025-10-22_07-23-44_LIBRARY_EVP-AKE31ASW_EVP-AKE3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; 2025-10-22_07-23-44_LIBRARY_SW_EVP-AKE31A_PAN
TP_BAT_GND: HECTOR_WATCH_1_TPTP20R; HECTOR_WATCH_1_TP20R
TP_ON: HECTOR_WATCH_1_TPTP20R; HECTOR_WATCH_1_TP20R
TP_OP: HECTOR_WATCH_1_TPTP20R; HECTOR_WATCH_1_TP20R
TP_VBAT: HECTOR_WATCH_1_TPTP20R; HECTOR_WATCH_1_TP20R
U3: MAX17048G+T10; ESP32_C6_LIBRARY_SON50P200X200X80-9N

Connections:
3V3: C34.2, IC2.C2 (VDD), Q1.2 (S), R5.2, R7.2, R8.2, R_PWR_EPD.2; also elsewhere on the board
ALERT: U3.5 (!ALERT); also elsewhere on the board
D+: D3.4 (I/O2_2); also elsewhere on the board
D-: D3.6 (I/O1_2); also elsewhere on the board
DN: D3.1 (I/O1_1), J4.A7 (DN1), J4.B7 (DN2)
DP: D3.3 (I/O2_1), J4.A6 (DP1), J4.B6 (DP2)
EPD_3V3: C1-EP-DR.1, EPD_C5.2, J1.15, J1.16, L5.2, Q1.3 (D)
EPD_BUSY: J1.9; also elsewhere on the board
EPD_CS: J1.12; also elsewhere on the board
EPD_DC: J1.11; also elsewhere on the board
EPD_RST: J1.10; also elsewhere on the board
GDR: J1.2, Q3.1 (G), R2_EP_DR.2
GND: C1-EP-DR.2, C27.1, C29.1, C30.1, C31.1, C32.1, C34.1, C42.1, C43.2, D3.2 (GND), D4.1 (K), EPD_C1.1, EPD_C2.1, EPD_C5.1, EPD_C6.1, EPD_C7.1, EPD_C8.1, EPD_C9.1, EPD_C10.1, EPD_C11.1, EPD_C12.1, IC2.B1 (IN/TRIG), IC2.B3 (GND), J1.8, J1.17, J1.MP1, J1.MP2, J4.A1_B12 (GND), J4.A12_B1 (GND), J4.SH1 (SHIELD), J4.SH2 (SHIELD), J4.SH3 (SHIELD), J4.SH4 (SHIELD), R1_USB.1, R2_EP_DR.1, R2_USB.2, R_TYPE_SEL.1, SJ1.1, SW_DN.1, SW_ENT.1, SW_UP.1, TP_BAT_GND.TP, U3.1 (CTG), U3.4 (GND), U3.6 (QSTRT), U3.9 (EP); also elsewhere on the board
HAPTIC_EN: IC2.A1 (EN); also elsewhere on the board
MOSI: J1.14; also elsewhere on the board
unnamed: C2-EP-DR.2, D5.2 (A), L5.1, Q3.3 (D)
unnamed: C2-EP-DR.1, D2.1 (K), D4.2 (A)
unnamed: R1_EP_ED.1, R_TYPE_SEL.2, SJ1.2
unnamed: EPD_C2.2, J1.4
unnamed: C32.2, IC2.A2 (REG)
unnamed: EPD_C1.2, J1.5
unnamed: EPD_C6.2, J1.18
unnamed: EPD_C7.2, J1.19
unnamed: EPD_C8.2, J1.20
unnamed: EPD_C10.2, J1.22
unnamed: J4.A5 (CC1), R1_USB.2
unnamed: EPD_C12.2, J1.24
unnamed: J4.B5 (CC2), R2_USB.1
OUT+: IC2.A3 (OUT+), TP_OP.TP
OUT-: IC2.C3 (OUT-), TP_ON.TP
P0.13/1.5D: C30.2, R5.1, SW_UP.2
P0.14/1.5D: C31.2, R8.1, SW_ENT.2
P1.01/1.6C: Q1.1 (G), R_PWR_EPD.1
P1.02/1.6C: C29.2, R7.1, SW_DN.2
PREVGH: D5.1 (K), EPD_C9.2, J1.21
PREVGL: D2.2 (A), EPD_C11.2, J1.23
RESE: J1.3, Q3.2 (S), R1_EP_ED.2
SCK: J1.13; also elsewhere on the board
SCL/1.4C: IC2.C1 (SCL), U3.7 (SCL)
SDA/1.4C: IC2.B2 (SDA), U3.8 (SDA)
VBAT: C27.2, TP_VBAT.TP, U3.2 (CELL), U3.3 (VDD); also elsewhere on the board
VBUS: C42.2, C43.1, D3.5 (VBUS), J4.A4_B9 (VBUS), J4.A9_B4 (VBUS); also elsewhere on the board

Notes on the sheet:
DMG2305UX-7
E-Paper Drive Circuit
Haptic Driver
Fuel Gauge
Buttons
E-Paper Display Connector
USB C Connector & ESD Protection
E-Paper & Peripherals
InkTime v6

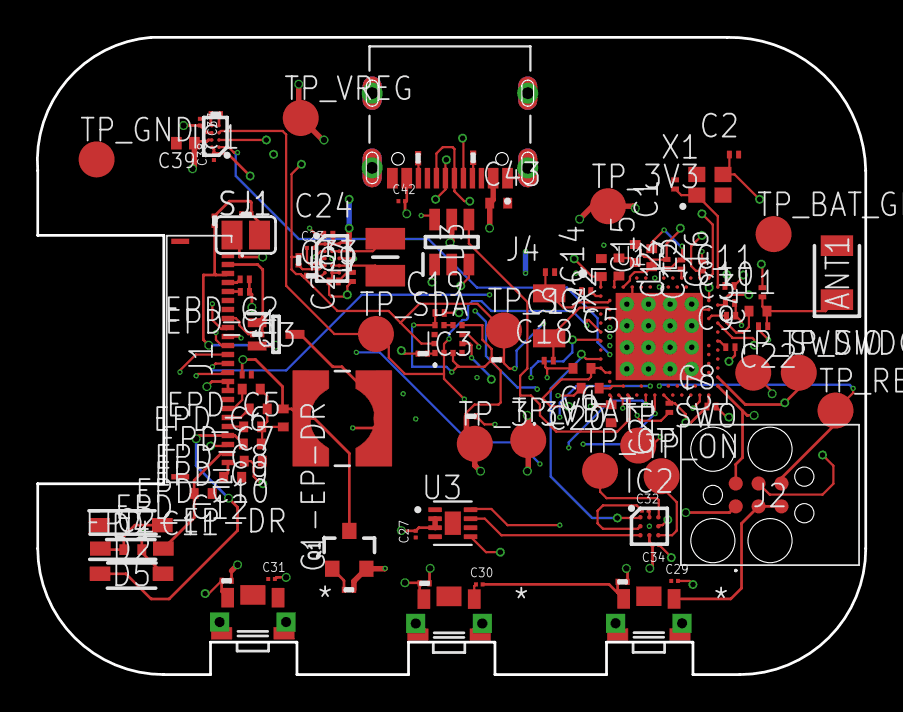
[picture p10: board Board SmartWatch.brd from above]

Board: 2 copper layers, 46.0 x 35.4 mm, 105 parts (0 on the bottom side), 73 nets.

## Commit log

2026-04-10 Initial commit: Adăugat schematic
    [Schematica.sch]
2026-04-10 Initialize README with project details and specifications
    Added detailed project overview, hardware architecture, BOM, technical details, and design log for InkTime smartwatch.
2026-04-20 Toate folderele si fisierele cerute
    [BOM.csv, Bill of Materials.csv, Board SmartWatch.brd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]

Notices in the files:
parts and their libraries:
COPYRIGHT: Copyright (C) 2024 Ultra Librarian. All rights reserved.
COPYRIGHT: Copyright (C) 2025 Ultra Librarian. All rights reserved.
